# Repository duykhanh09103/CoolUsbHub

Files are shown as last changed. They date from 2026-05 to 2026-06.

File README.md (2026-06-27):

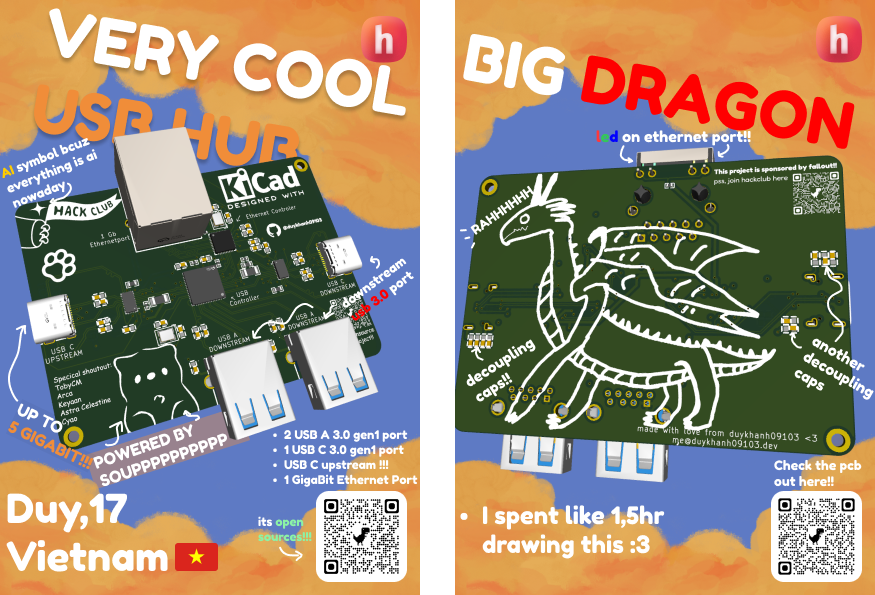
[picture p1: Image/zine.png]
Zine

# Very cool usb hub!!
its a 4 port\* usb 3.0 gen1 hub with usb c as a upstream port. It is fully open source and you can built it yourself!!! \
\*1 of its port is for 1gb ethernet

# Key Features
- Built in **1 Gigabit Ethernet** port using [REALTEK RTL8153B](https://www.lcsc.com/product-detail/C2802072.html)
- **2 USB A** and **1 USB C** 3.0 gen 1 downstream port
- **USB C upstream** so you can use **C to C** and **C to USB** cable!!!(with any length you want)
- Very cool art :3

# Why did i make it?
 currently theres literally no usb hub that does usb c 3.0 as upstream without having its cord built in, its bad and if the cord break u either throw it out or destroy the case to repair it.

# How to use it?
 💀 its an usb hub dude, just plug the usb c upstream to a pc and plug peripheral into the usb c and a port 😭

# 3D image 
- With case: (pss, check it out on [onshape](https://cad.onshape.com/documents/b8187d4a30cc3b22176f8391/w/6bf875d6f0e4efab8544a163/e/2b79dfe3cdb89a71b66a7f8a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))
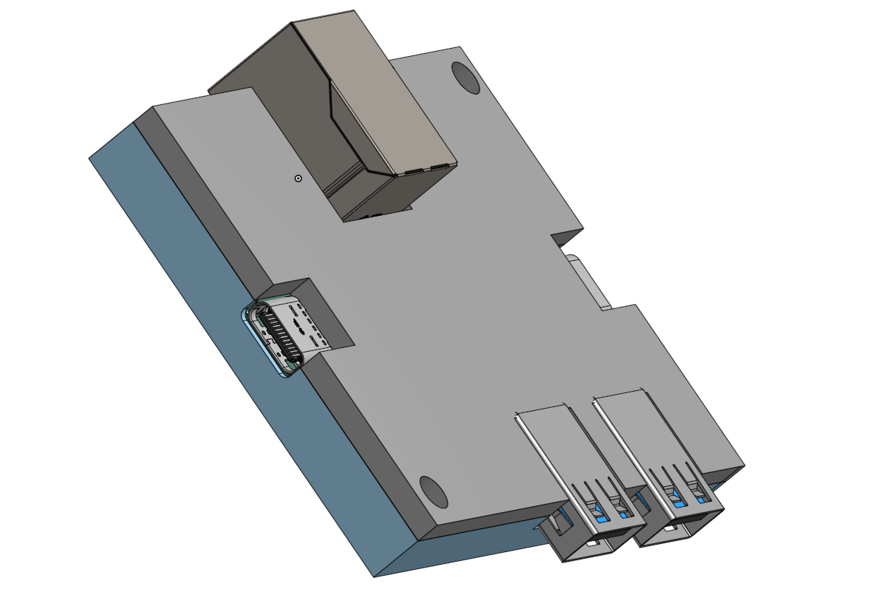
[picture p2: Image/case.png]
case


case 2!!

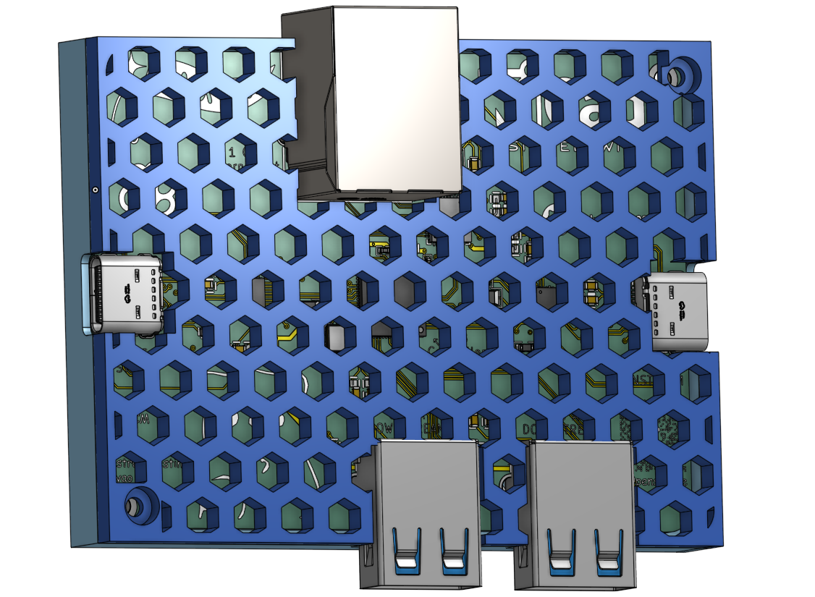
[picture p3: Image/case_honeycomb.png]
case_honeycomb


-Without case

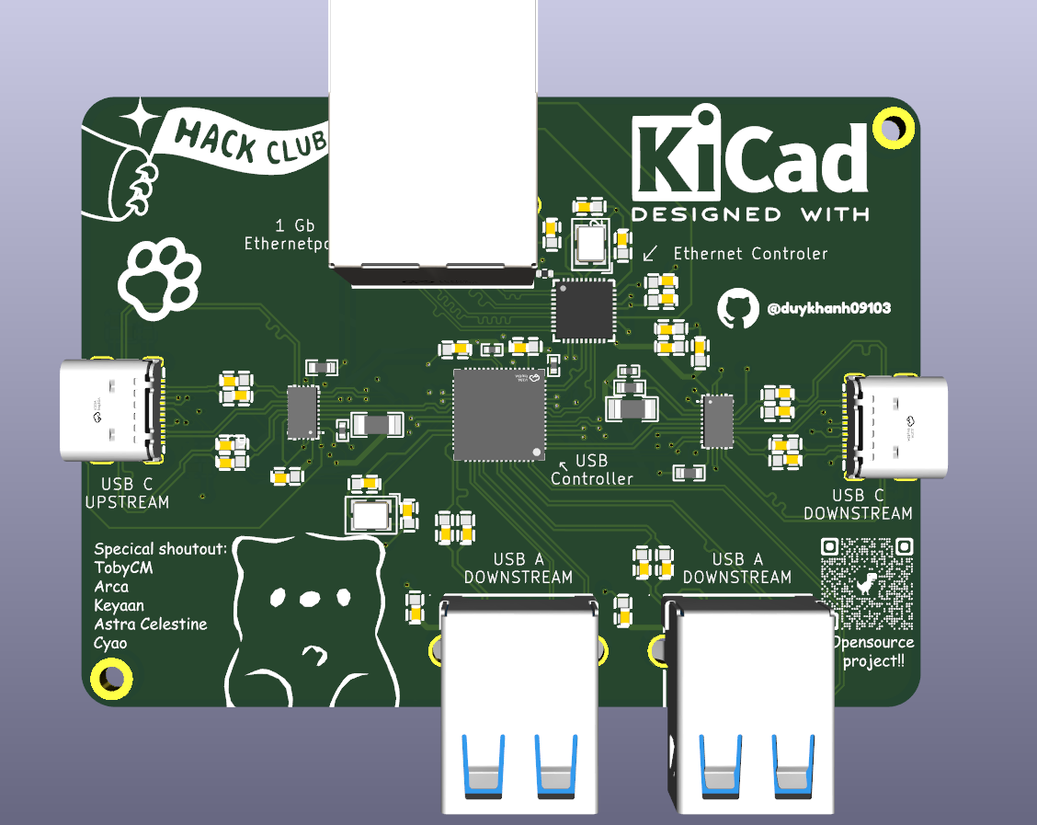
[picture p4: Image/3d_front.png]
3d image


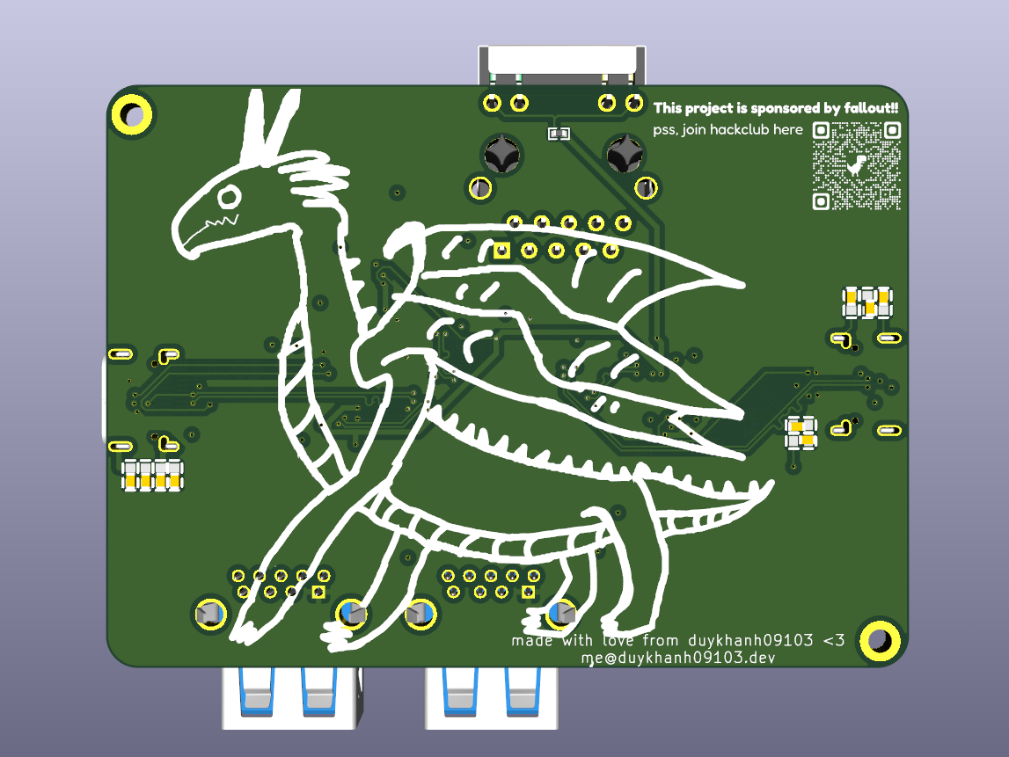
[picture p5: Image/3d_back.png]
3d back image


# SCHEMATIC
 check out the schematic [here](schematic.pdf) if the image is too blurry

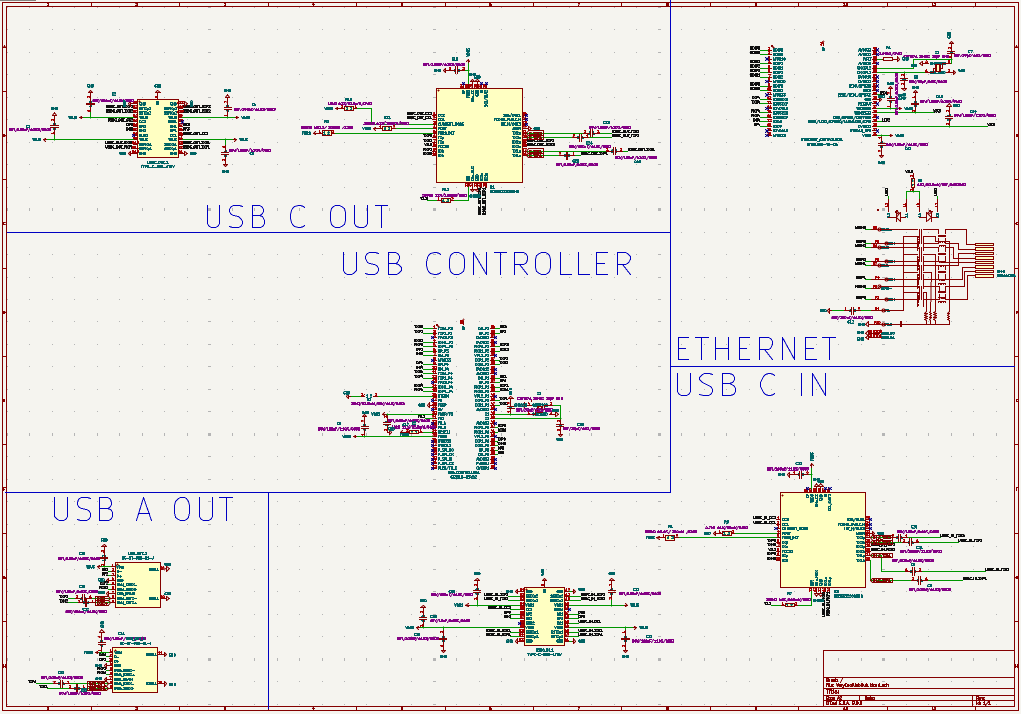
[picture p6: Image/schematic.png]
schematic
 
 
# PCB
 This is a 4 layer pcb made using [Kicad](https://www.kicad.org/), design with attention(😭) to signal intergrity for USB 3 trace! check it out with [kicanvas](https://kicanvas.org/?repo=https%3A%2F%2Fgithub.com%2Fduykhanh09103%2FCoolUsbHub%2Ftree%2Fmain%2Fpcb)!!
 - **Layer 1: signal**

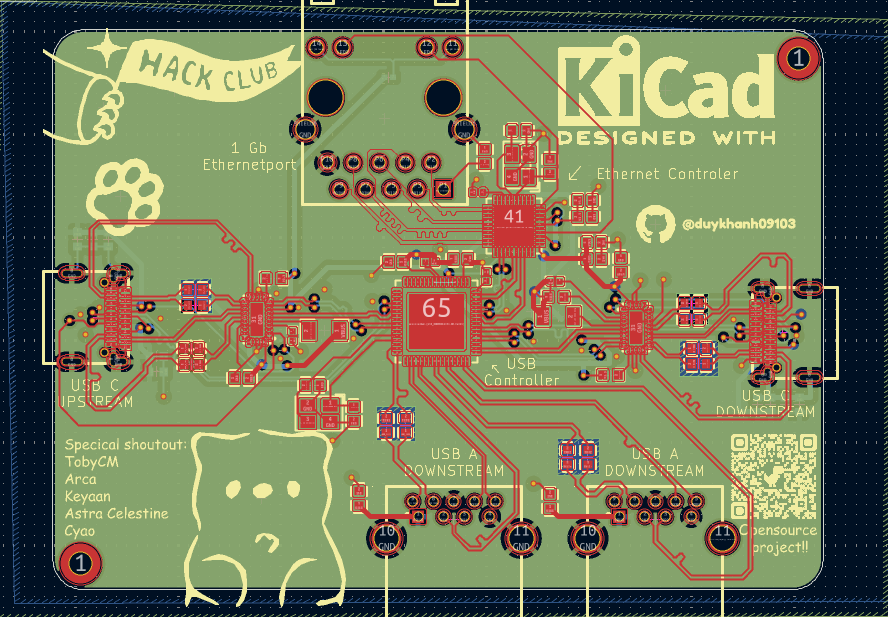
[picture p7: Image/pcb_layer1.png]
layer1
  
 - **Layer 2: Ground**

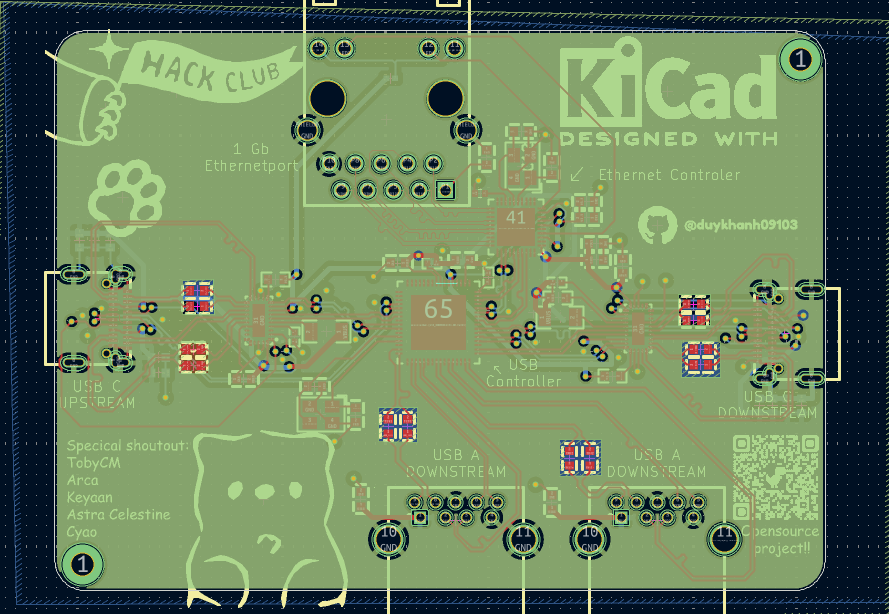
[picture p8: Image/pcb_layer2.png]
layer2
  
 - **Layer 3: Ground**

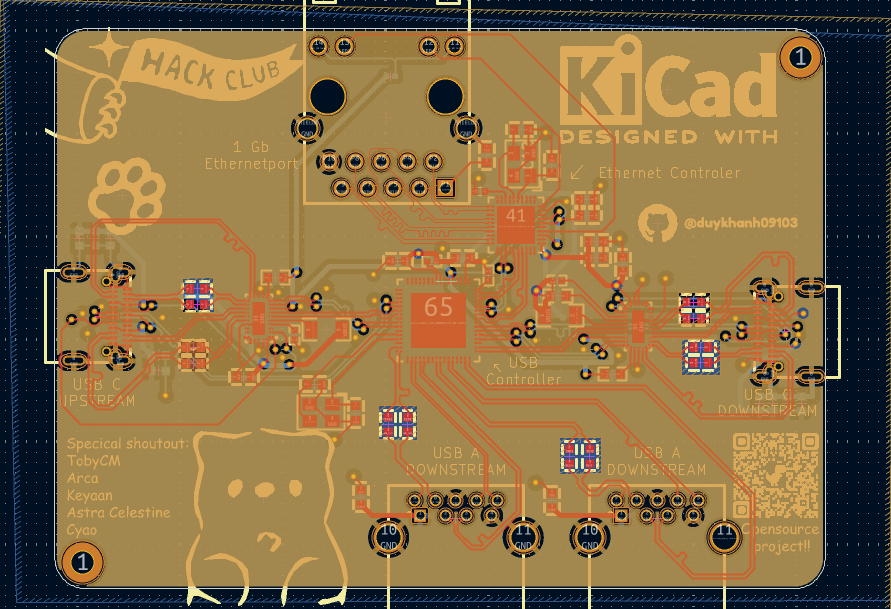
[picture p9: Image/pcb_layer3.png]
layer3
  
 - **Layer 4: Signal/Vbus**
 
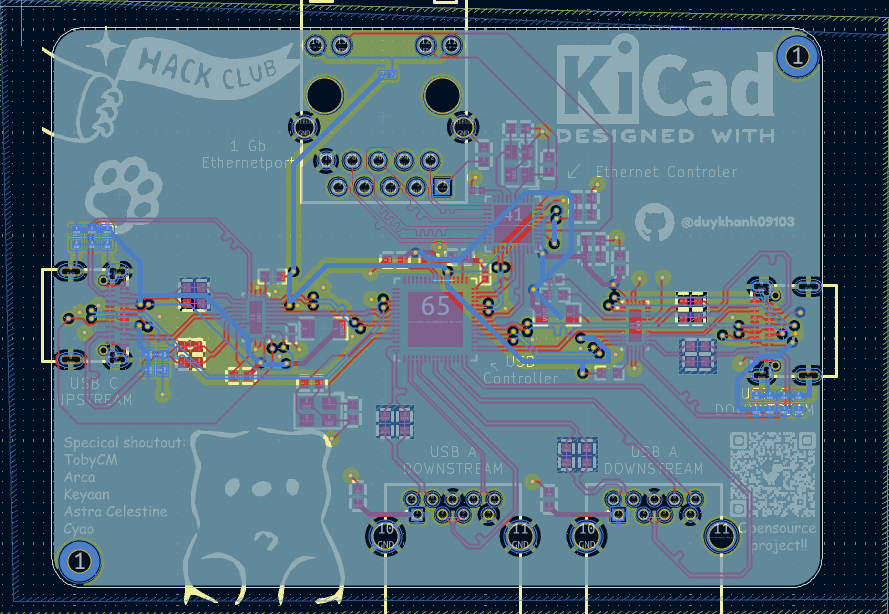
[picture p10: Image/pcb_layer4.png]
layer4
  

# BOM (Bill Of Materials)
> [!IMPORTANT]
> This is the total of the bom including both thing below, do not double count by combining them
> You can leave thing that you already have out of the bom to reduce cost

> [!TIP]
> For any hcer reading this, there is jlc and lcsc cart image in /Image

| Name | Amount | Price | Source/Where To Buy | Note |
|---|---|---|---|---|
| PCB | 5 | $12 | JLCPCB | 4 layer, specify 3313 in stackup(i got white so its 12$) |
| 3D Printed Case | 2 | $2.74 | JLC3DP | |
| PCB Parts | 2 | $30.86| LCSC | |
| Tools and miscellaneous | 1 | $22 | | |
| Shipping | | $11 | | |
| Coupon from fallout | | -$15  | | |
| | | | | |
| Total | | $63.6 | | |

## PCB Parts
> [!IMPORTANT]
> This will include how much components you need to use per 1 PCB and the MOQ (minimum of quanity) you can buy. The price will be listed in MOQ. The final price is included everything except shipping.

> [!WARNING]
>  There might be different capacitor/resistor part from production bom because of out of stock

| Name | Amount | MOQ |  Price  | Note | LCSC Number |
|---|---|-----|---|---|---|
| 39pf 50v 0603 Capacitor | 4 | 100 | $0.48 | | C107049 |
| 10uF 10v 0603 Capacitor | 1 | 20  | $0.53 | | C19702 |
| RTL8153B-VB-CG | 1 | 1 | $3.64 | Ethernet chip (1gb)  | C2802072 |
| 20kΩ 62.5mW 0402 Resistor | 3 | 100 | $0.10 | | C93942 |
| 4.7kΩ 63mW 0402 Resistor  | 1 | 100 | $0.44 | | C509343 |
| RJ45 Jack | 1 | 1 | $2.51 | | C54408 |
| HD3SS3220RNHR | 2 | 1 | $1.9032 | USB TYPE C MUX | C165155 |
| Type C Receptacle | 2 | 5 | $1.60 | on sale | C20883027 |
| GL3510-OSY52 | 1 | 1 | $1.46 | USB HUB | C7501408 |
| Type A Receptacle | 2 | 5 | $0.66 | | C2845330 |
| 25MHz 20pf crystal | 2 | 10  | $0.98 | | C13740 |
| 900kΩ 250mW 1206 Resistor | 1 | 10  | $0.63 | | C871726 |
| 10kΩ 62.5mW 0402 Resistor | 2 | 100 | $0.27 | | C2906861 |
| 1kΩ 62.5mW 0402 Resistor  | 1 | 50  | $0.89 | | C852624 |
| 200kΩ 100mW 0603 Resistor | 2 | 100 | $0.22 | on sale | C2907009 |
| 100nF 50V 0603 Capacitor  | 31 | 50  | $0.92 | | C282518 |
| 2.49k X 0402 Resistor | 1 | 100 | 15k VND | I got it from shopee | X |
| | | | | | |
| Total | | | $19.44  | | |

## Tool and miscellaneous
> [!NOTE]
> If you have the tool already or wanna do this differently, you do not need to buy these

| Name | Amount |  Price | Source |
|---|---|---|---|
| Hot air gun | 1 | $21 | Lazada |
| Flux | 1 | $1 | Shopee |
| Pinecil | 1 | $25.99 | Pinecil official website |
| Solder paste/wire | 1 | $1 | Idk its everywhere |

# How to build??? (soon 👀)
- Order pcb from jlc/any pcb vendor with gerber.zip inside /pcb/production
- there will be video on building one soon

# Credit
 Shoutout to [@tobycm](https://github.com/tobycm) for being the goat and help me a lot with ts project <3\
 This project use kicad, onshape for designing case and pcb\
 Thanks to [Hackclub](https://hackclub.com/) , especially to people running [Fallout](https://fallout.hackclub.com/) for making this project possible :3

# LICENSE
its [MIT](https://opensource.org/license/mit)!! (basically u can do anything with ts). checkout [LICENSE](LICENSE)

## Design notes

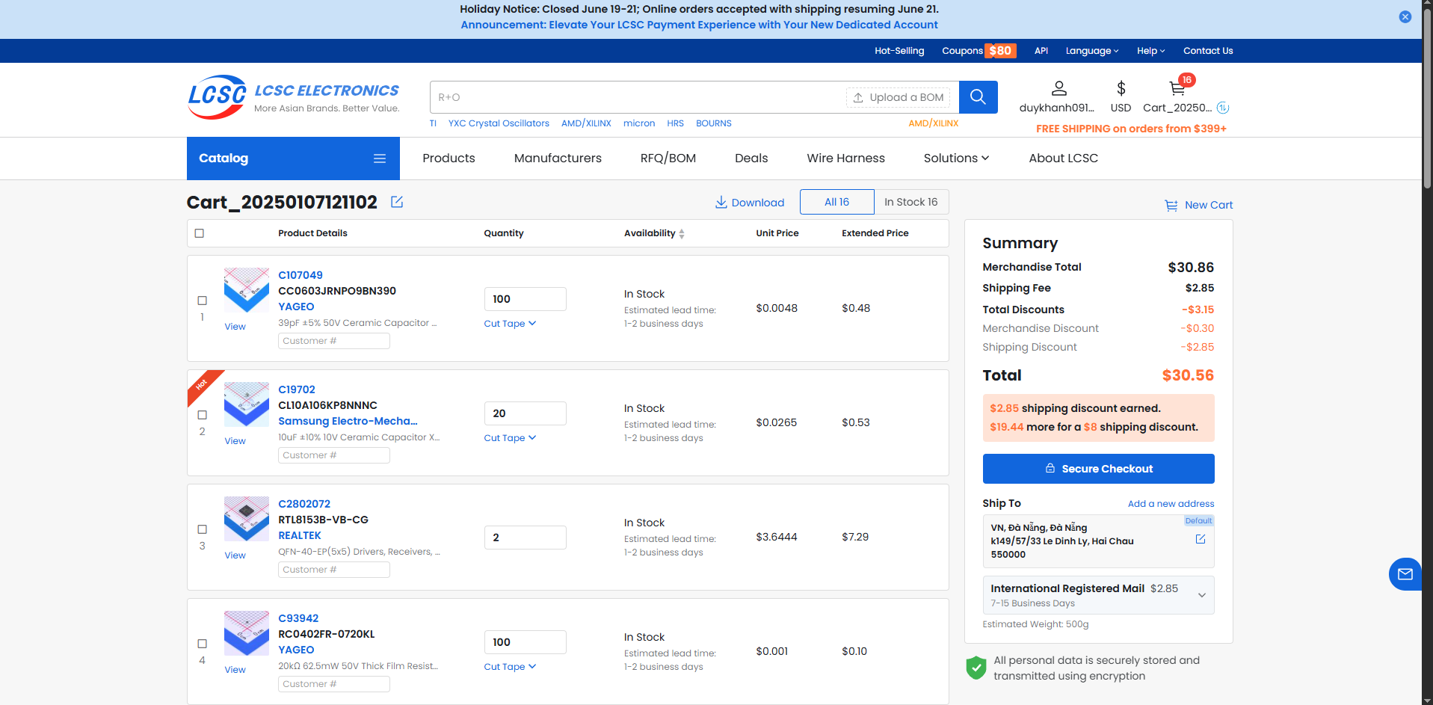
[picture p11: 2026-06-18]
Image/lcsc_cart.png

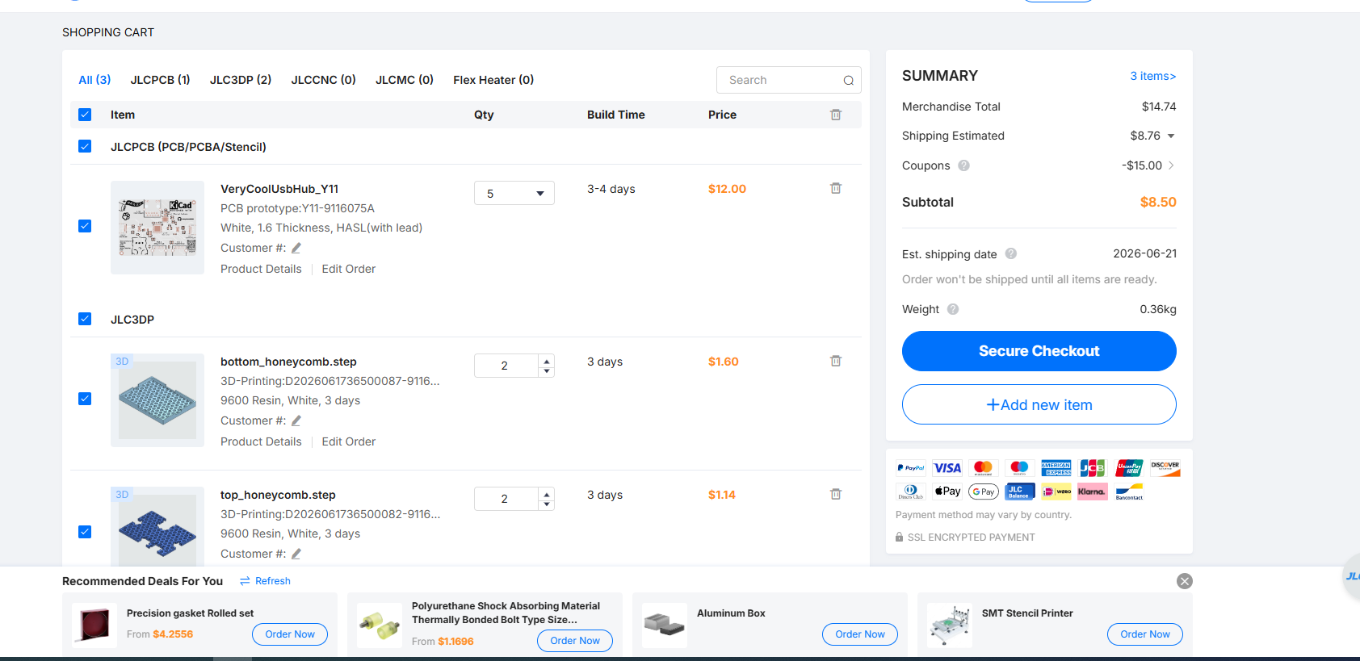
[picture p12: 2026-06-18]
Image/jlc_cart.png

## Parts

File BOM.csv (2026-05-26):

Part | Amount | Price | Link
PCB | 5 | $7 | jlcpcb.com/
100nF Capacitor | 31 | $0.35 | https://www.lcsc.com/product-detail/C14663.html
39 pF Capacitor | 4 | $0.32 | https://www.lcsc.com/product-detail/C107049.html
10 uF Capacitor | 1 | $0.25 | https://www.lcsc.com/product-detail/C19702.html
Ethernet Adapter | 1 | $4.26 | https://www.lcsc.com/product-detail/C2802072.html
10k ohm resistor | 2 | $0.09 | https://www.lcsc.com/product-detail/C60490.html
200k ohm resistor | 2 | $0.16 | https://www.lcsc.com/product-detail/C105574.html
20k ohm resistor | 3 | $0.10 | https://www.lcsc.com/product-detail/C93942.html
1k ohm resistor | 1 | $0.09 | https://www.lcsc.com/product-detail/C106235.html
4.7 k ohm resistor | 1 | $0.34 | https://www.lcsc.com/product-detail/C509343.html
2.49k ohm resistor | 1 | $0.57 | https://shopee.vn/Tr%E1%BB%9F-d%C3%A1n-0402-tr%E1%BB%8B-s%E1%BB%91-trong-2K-(-2K-2.2K-2.26K-2.32K-2.49K-2.55K-2.61K-2.67K-2.7K-2.74K-2.8K-2.87K-)-d%C3%B9ng-ch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
RJ45 connector | 1 | $2.51 | https://www.lcsc.com/product-detail/C54408.html
USB C mux | 2 | $3.89 | https://www.lcsc.com/product-detail/C165155.html
USB C receptacle | 2 | $1.48 | https://www.lcsc.com/product-detail/C20883027.html
USB Controller | 1 | $1.46 | https://www.lcsc.com/product-detail/C7501408.html
25mhz Crystal | 2 | $0.75 | https://www.lcsc.com/product-detail/C13740.html
900k ohm resistor | 1 | $0.45 | https://www.lcsc.com/product-detail/C871726.html
USB A receptacle | 2 | $0.65 | https://www.lcsc.com/product-detail/C2845330.html
Total |  | 24.11$ (shipping not included)

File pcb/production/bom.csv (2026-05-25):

Designator | Footprint | Quantity | Value | LCSC Part #
C1, C10, C11, C12, C13, C14, C15, C16, C17, C19, C2, C20, C21, C22, C23, C24, C26, C29, C3, C30, C31, C32, C33, C34, C35, C36, C37, C4, C5, C8, C9 | C0603 | 31 | CC0603KRX7R9BB104 | C14663
C18, C25, C6, C7 | C0603 | 4 | CC0603JRNPO9BN390 | C107049
C28 | C0603 | 1 | CL10A106KP8NNNC | C19702
ETHERNET_CONTROLLER1 | QFN-40_L5.0-W5.0-P0.40-BL-EP3.7 | 1 | RTL8153B-VB-CG | C2802072
R1, R9 | R1206 | 2 | RT1206BRE07900KL | C871499
R10, R2 | R0402 | 2 | RC0402FR-0710KL | C60490
R11, R12, R7 | R0603 | 3 | RC0603FR-07200KL | C105574
R3 | R0402 | 1 | RC0402FR-0720KL | C93942
R4 | 0402 | 1 | R
R6 | R0402 | 1 | RC0402FR-071KL | C106235
R8 | R0402 | 1 | MCR01MZPF4701 | C509343
RJ45 | RJ45-TH_HR911130A | 1 | HR911130A | C54408
U1, U2 | WQFN-30_L4.5-W2.5-P0.4-BL-EP | 2 | HD3SS3220RNHR | C165155
USBC_IN_1, USBC_OUT_1 | USB-C-SMD_TYPE-C-G05-1TDW | 2 | TYPE-C-G05-1TDW | C20883027
USB_CONTROLLER1 | QFN-64_L8.0-W8.0-P0.40-BL-EP5.4 | 1 | GL3510-OSY52 | C7501408
USB_OUT_1, USB_OUT_2 | USB-3.0-A-TH_HC-ST-003-01-Z | 2 | HC-ST-003-01-J | C2845330
X1, X2 | CRYSTAL-SMD_4P-L3.2-W2.5-BL-2 | 2 | X322525MSB4SI | C13740

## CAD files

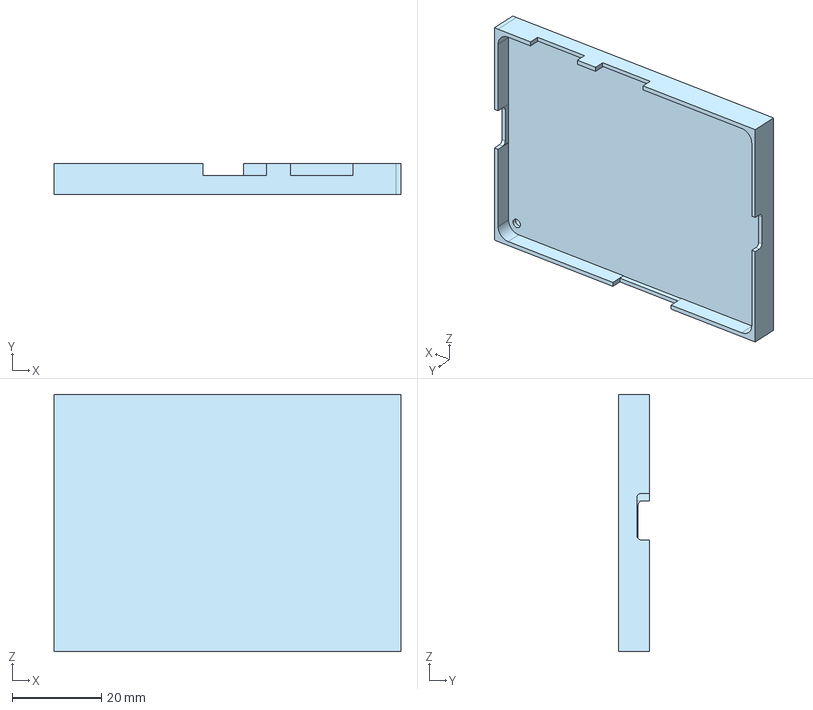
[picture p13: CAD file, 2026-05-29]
3d/bottom.step
77.8 x 7.00 x 57.7 mm

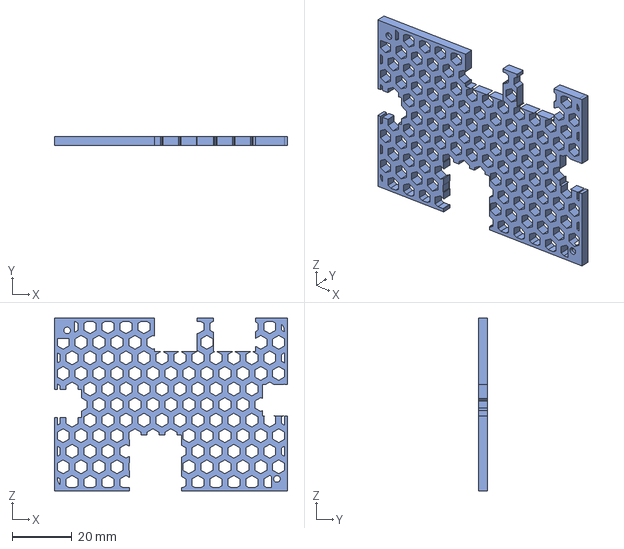
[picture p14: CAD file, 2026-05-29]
3d/top_honeycomb.step
77.8 x 3.00 x 57.7 mm

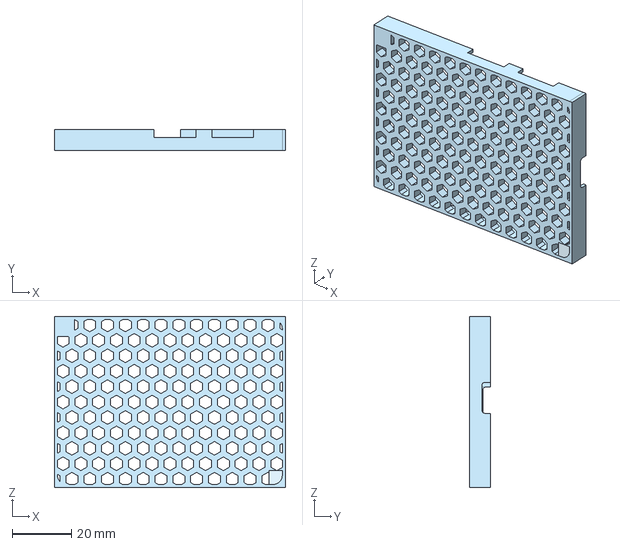
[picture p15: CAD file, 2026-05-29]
3d/bottom_honeycomb.step
77.8 x 7.00 x 57.7 mm

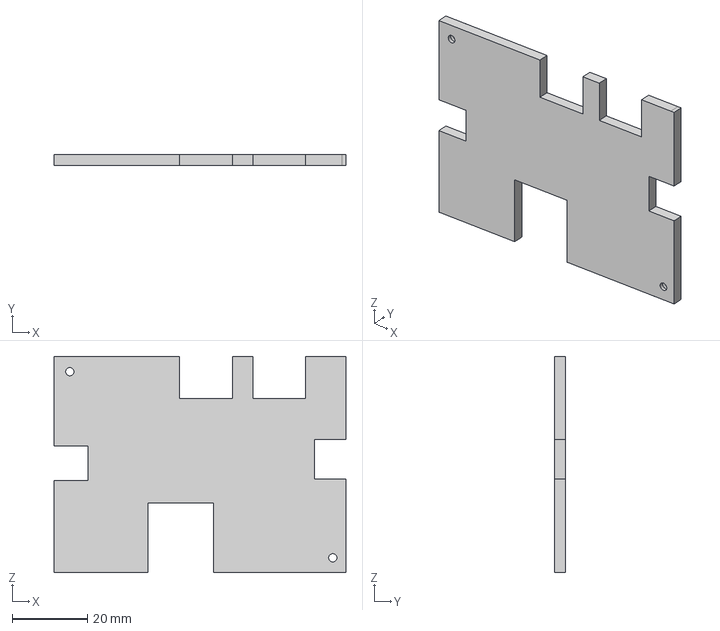
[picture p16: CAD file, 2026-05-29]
3d/top.step
77.8 x 3.00 x 57.7 mm

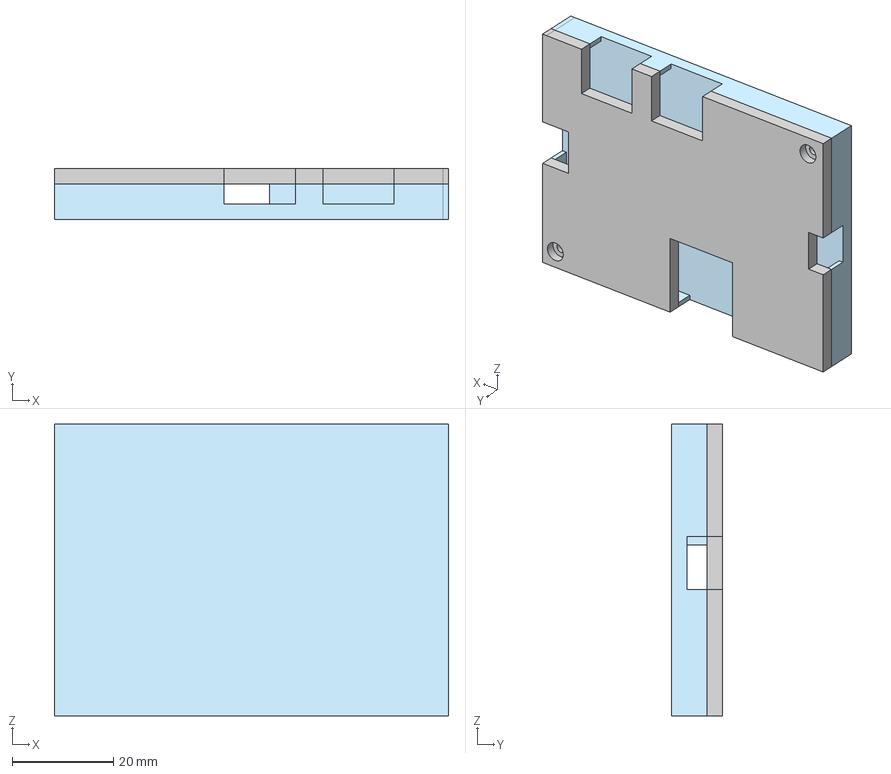
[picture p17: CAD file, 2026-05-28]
3d/case.step
77.8 x 10.0 x 57.7 mm

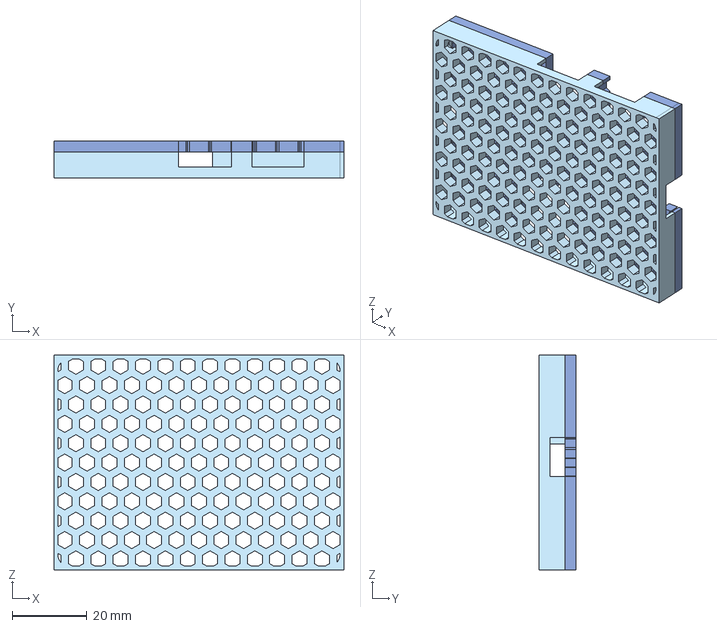
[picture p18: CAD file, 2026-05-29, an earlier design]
3d/old_unpolished/case_honeycomb.step
77.8 x 10.0 x 57.7 mm

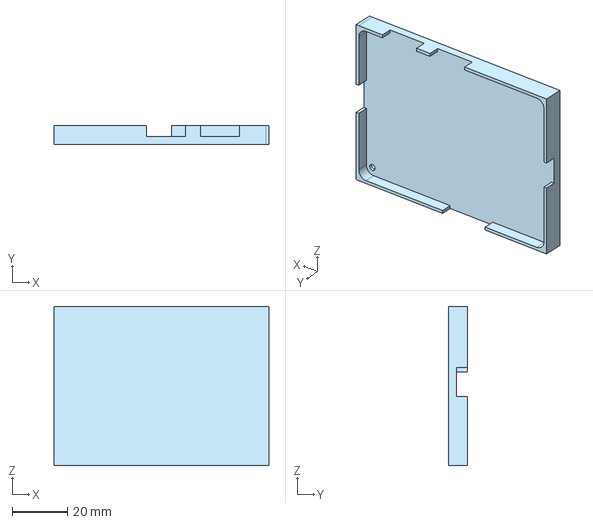
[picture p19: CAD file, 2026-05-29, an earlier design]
3d/old_unpolished/bottom.step
77.8 x 7.00 x 57.7 mm

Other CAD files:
3d/Assembly_case.step
3d/Assembly_honeycomb_case.step
3d/old_unpolished/Bottom_honeycomb.step
3d/old_unpolished/top.step
3d/old_unpolished/Top_honeycomb.step

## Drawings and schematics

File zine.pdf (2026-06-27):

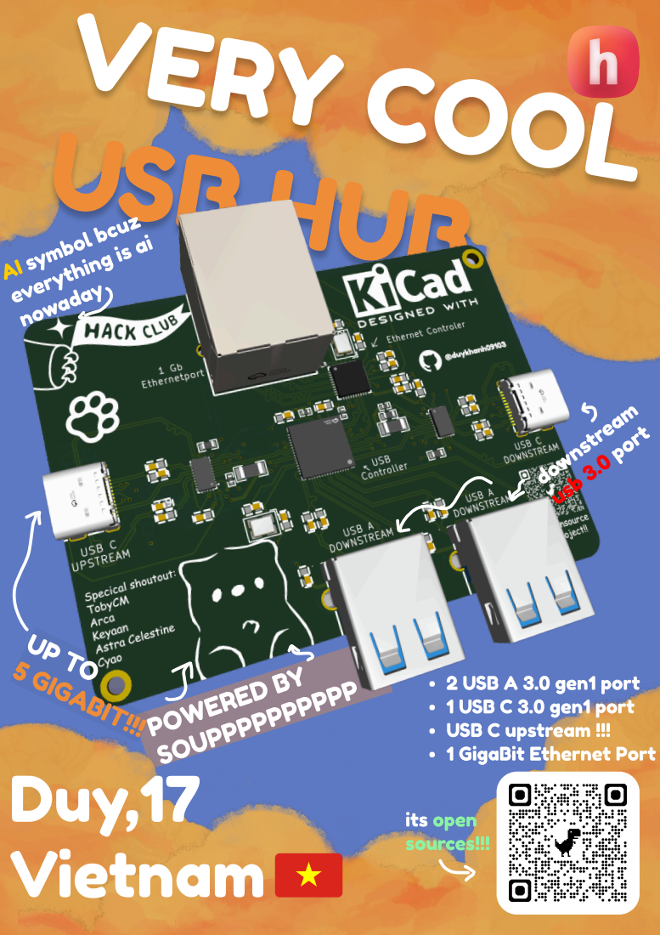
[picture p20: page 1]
nowaday; VERY COOL USB HUB; downstream usb 3.0 port; UP TO 5 GIGABIT!!!; Duy,17; Vietnam; POWERED BY SOUPPPPPPPPPP; its open; sources!!!

AI symbol bcuz

everything is ai

2 USB A 3.0 gen1 port
1 USB C 3.0 gen1 port
USB C upstream !!!
1 GigaBit Ethernet Port

### led on ethernet port!!

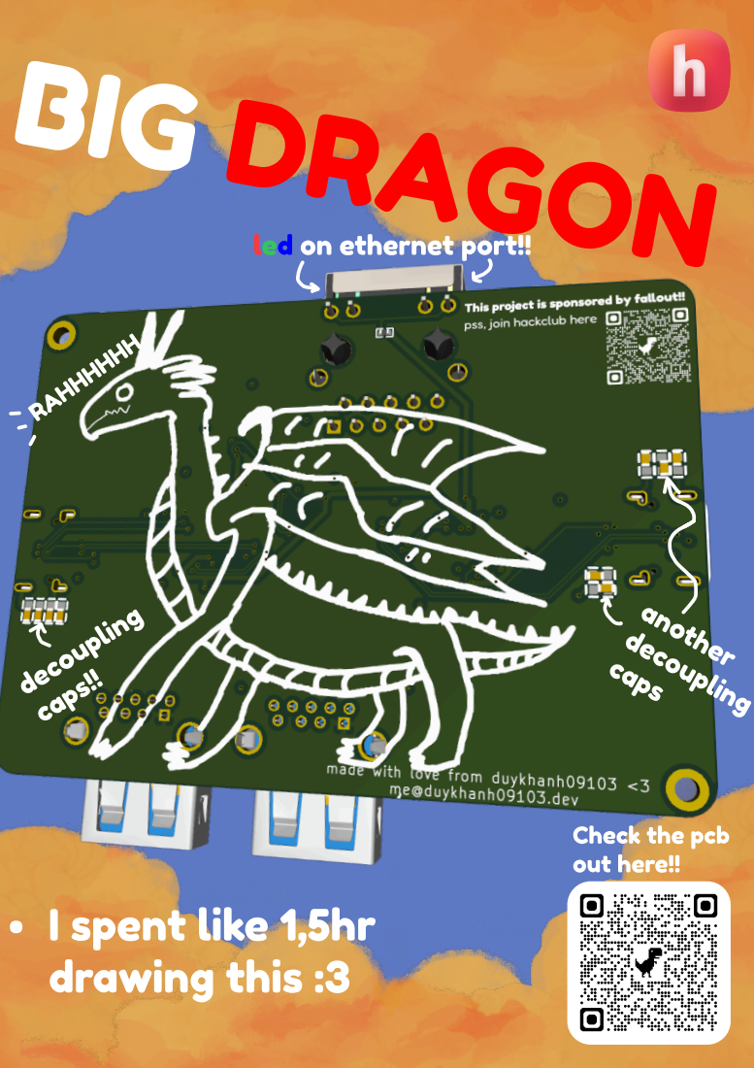
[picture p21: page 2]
BIG DRAGON; RAHHHHHH; decoupling; caps!!; another decoupling caps; I spent like 1,5hr; drawing this :3

Check the pcb
out here!!

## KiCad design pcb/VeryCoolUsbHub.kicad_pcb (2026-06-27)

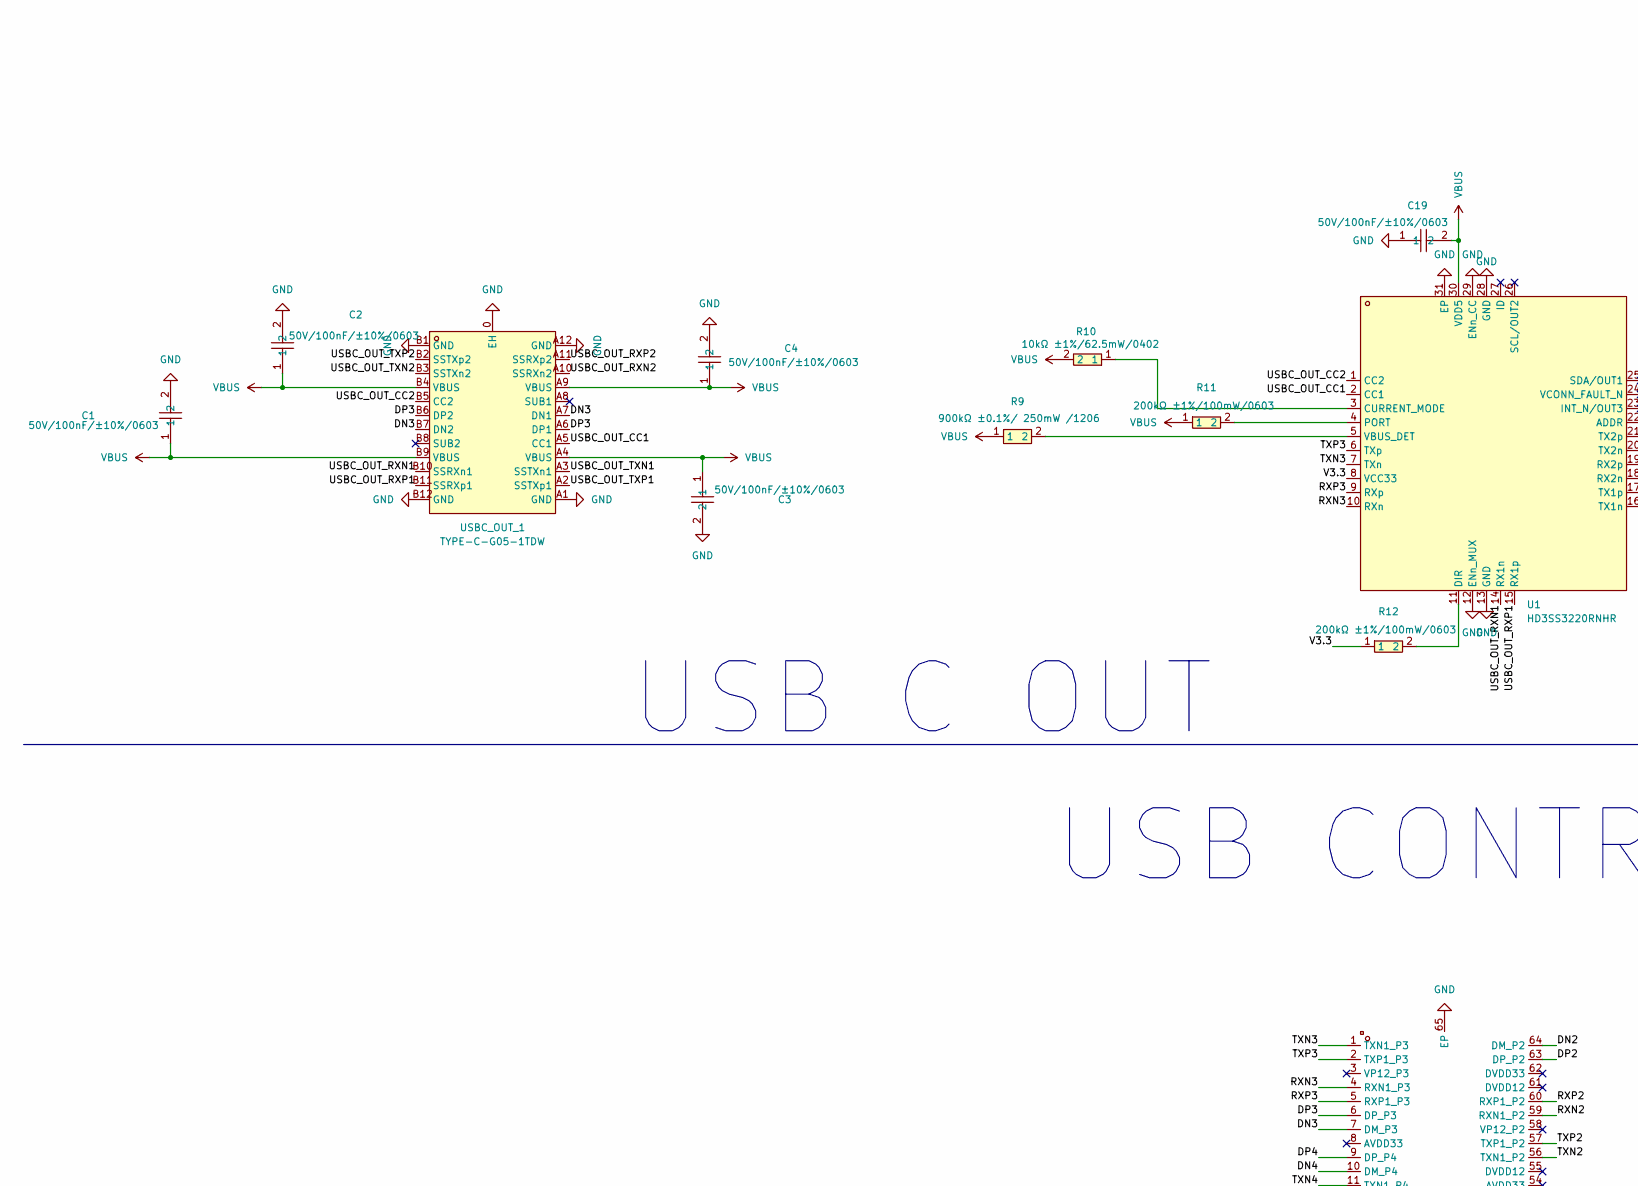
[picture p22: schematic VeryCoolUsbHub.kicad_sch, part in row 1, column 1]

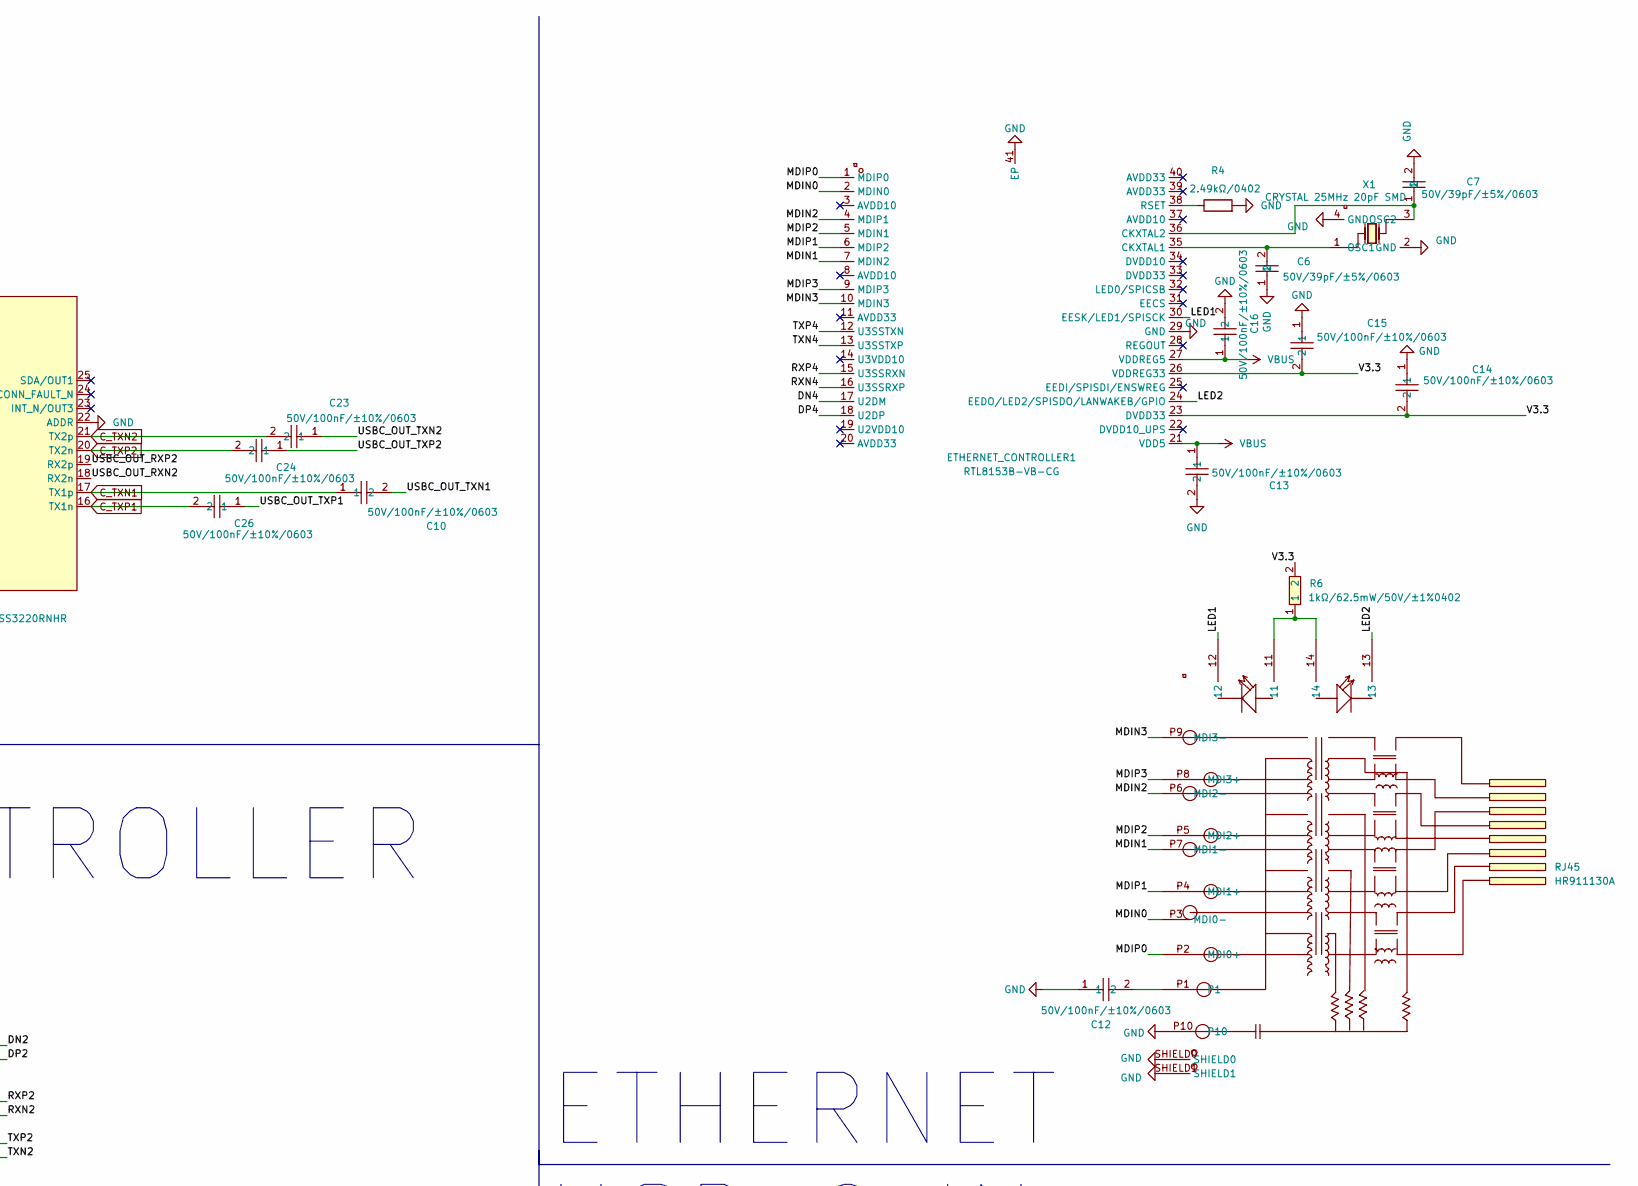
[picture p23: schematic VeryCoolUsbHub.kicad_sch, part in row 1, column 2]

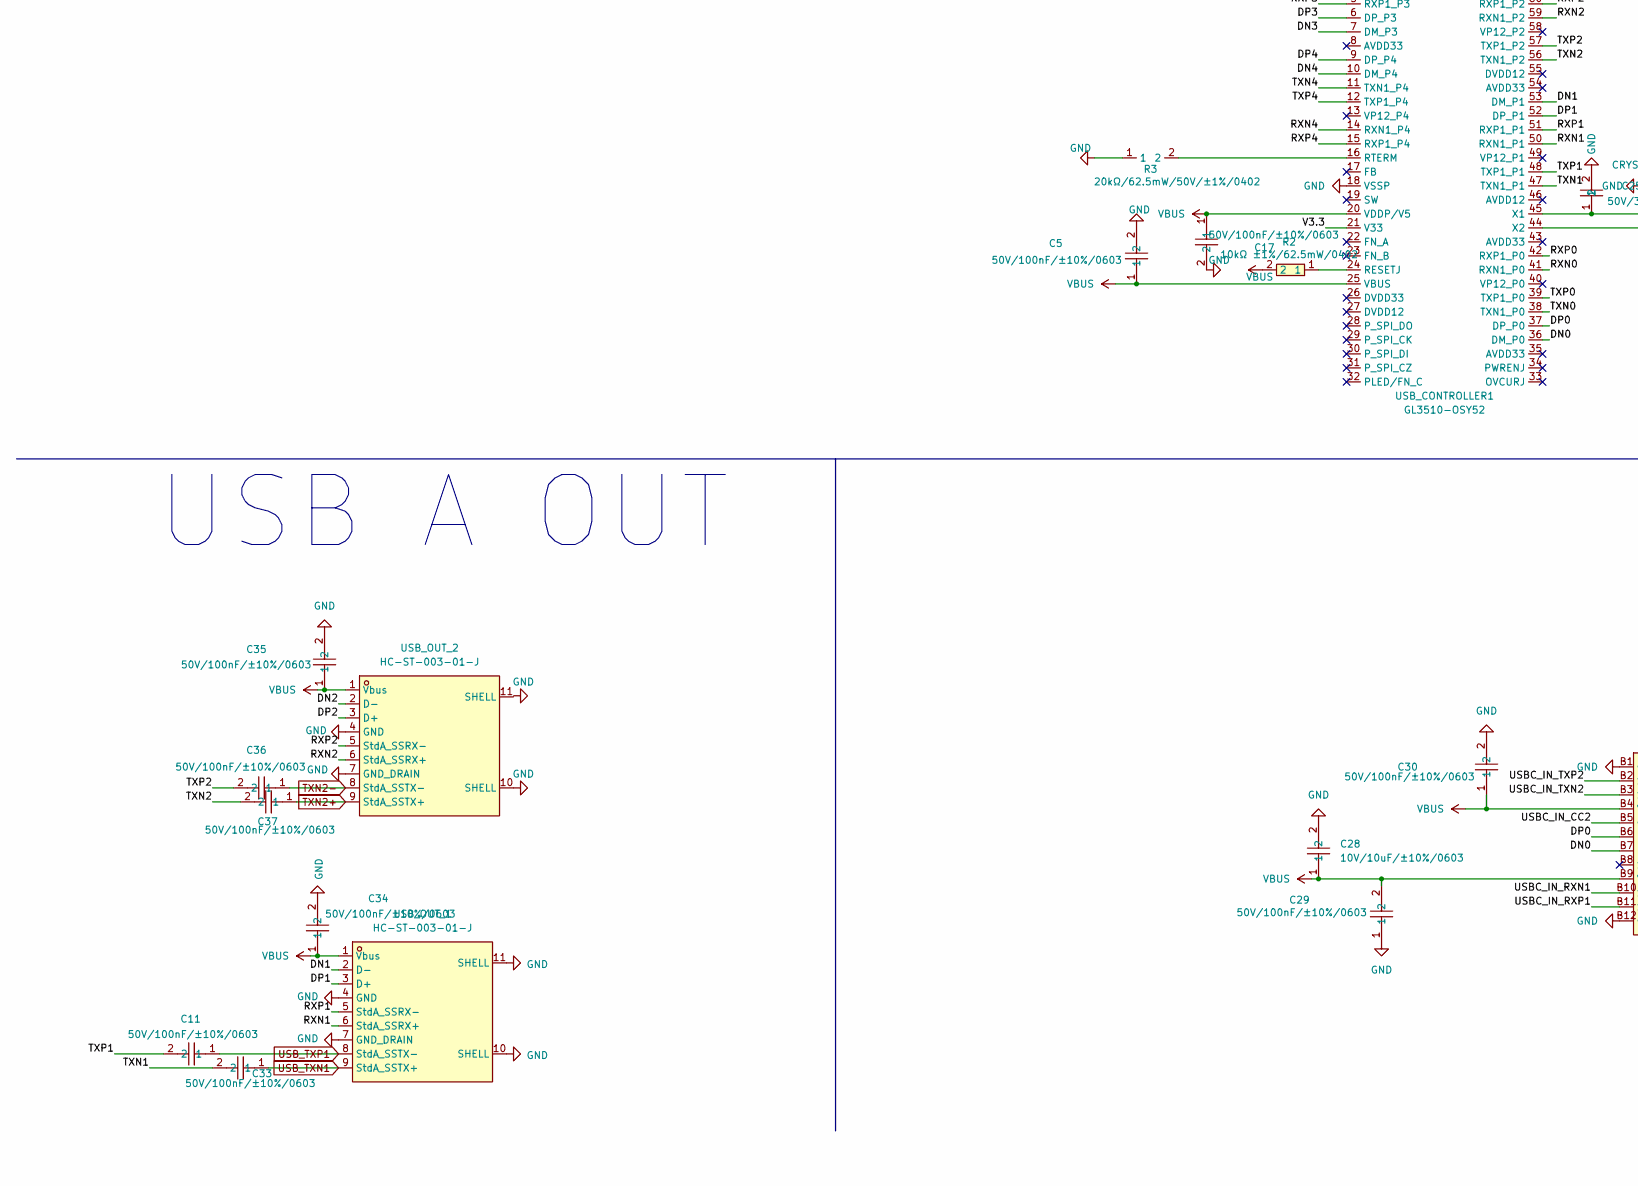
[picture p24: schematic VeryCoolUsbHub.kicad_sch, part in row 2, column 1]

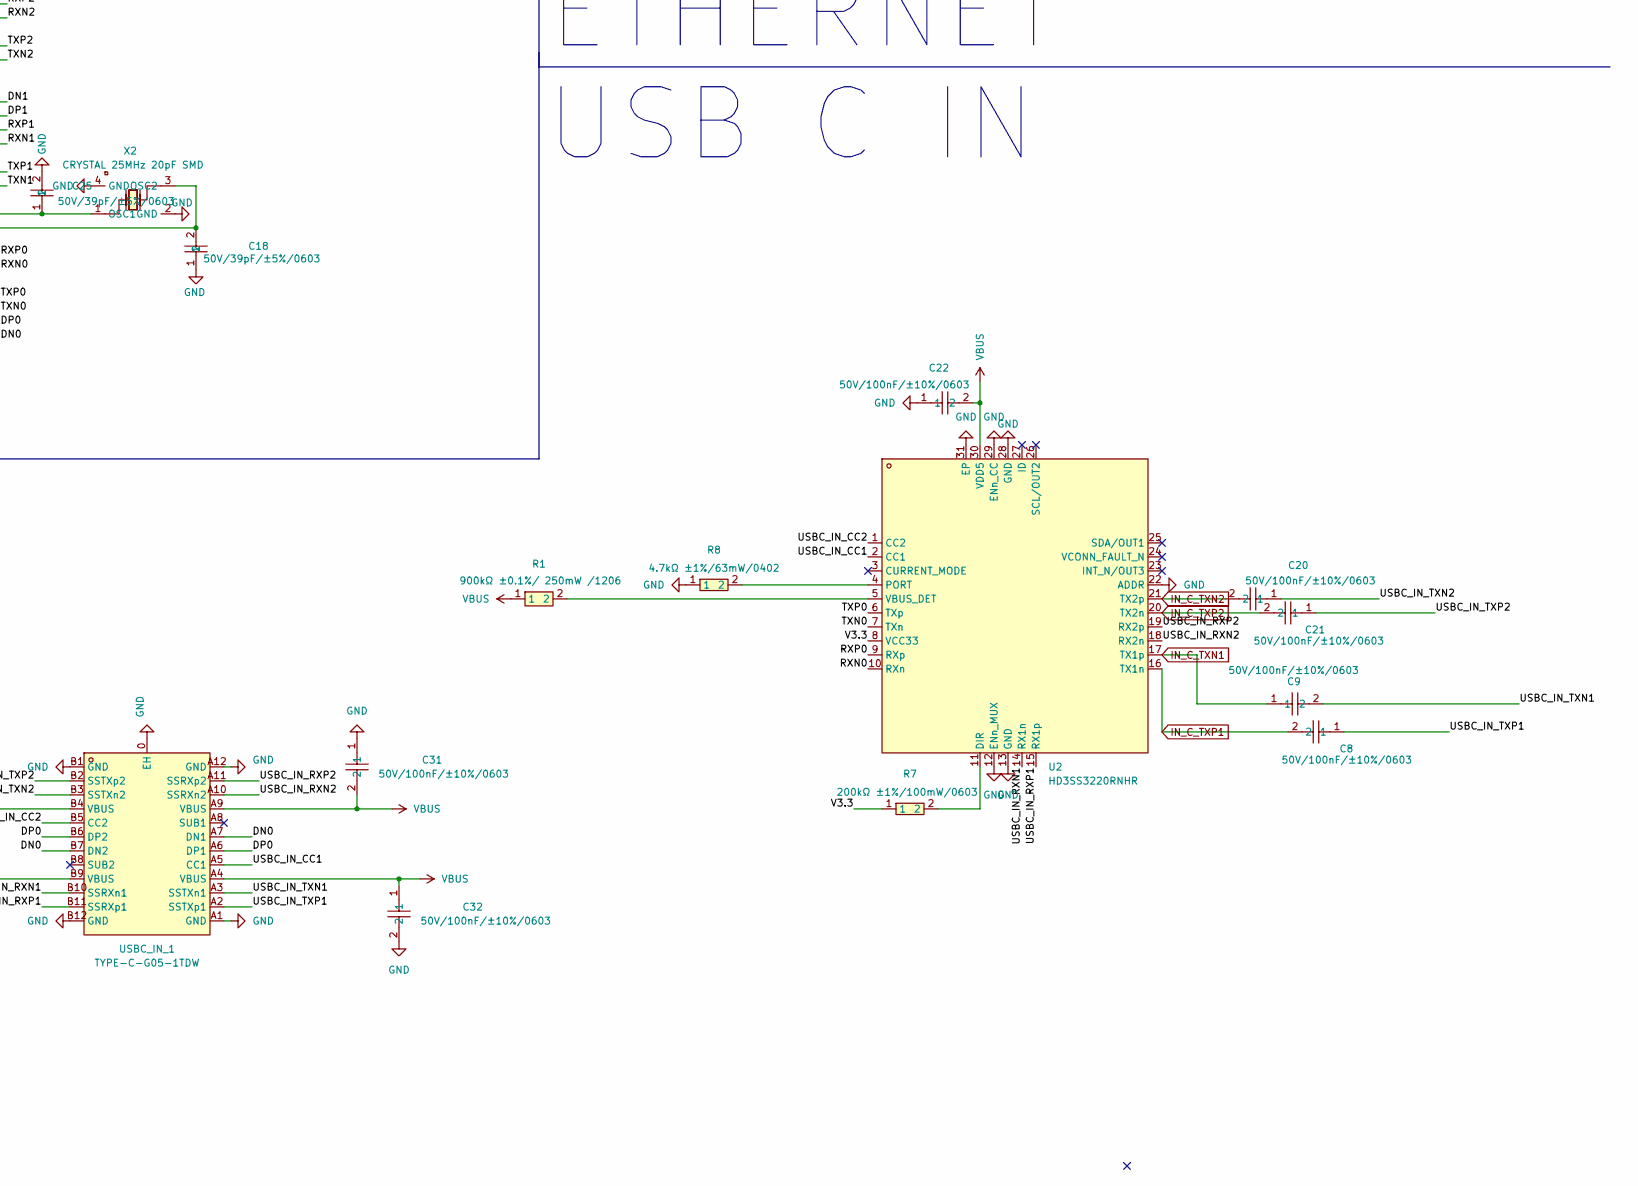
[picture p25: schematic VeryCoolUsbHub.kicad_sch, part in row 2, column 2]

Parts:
C1, C2, C3, C4, C5, C8, C9, C10, C11, C12, C13, C14, C15, C16, C17, C19, C20, C21, C22, C23, C24, C26, C29, C30, C31, C32, C33, C34, C35, C36, C37: CC0603KRX7R9BB104; C0603; LCSC Part C14663
C6, C7, C18, C25: CC0603JRNPO9BN390; C0603; LCSC Part C107049
C28: CL10A106KP8NNNC; C0603; LCSC Part C19702
ETHERNET_CONTROLLER1: RTL8153B-VB-CG; QFN-40_L5.0-W5.0-P0.40-BL-EP3.7; LCSC Part C2802072
R1, R9: RT1206BRE07900KL; R1206; MPN RT1206BRE07900KL; LCSC Part C871499
R2, R10: RC0402FR-0710KL; R0402; MPN RC0402FR-0710KL; LCSC Part C60490
R3: RC0402FR-0720KL; R0402; LCSC Part C93942
R4: R; R_0402_1005Metric
R6: RC0402FR-071KL; R0402; LCSC Part C106235
R7, R11, R12: RC0603FR-07200KL; R0603; MPN RC0603FR-07200KL; LCSC Part C105574
R8: MCR01MZPF4701; R0402; MPN MCR01MZPF4701; LCSC Part C509343
RJ45: HR911130A; RJ45-TH_HR911130A; LCSC Part C54408
U1, U2: HD3SS3220RNHR; WQFN-30_L4.5-W2.5-P0.4-BL-EP; MPN HD3SS3220RNHR; LCSC Part C165155
USBC_IN_1: TYPE-C-G05-1TDW; USB-C-SMD_TYPE-C-G05-1TDW; MPN TYPE-C-G05-1TDW; LCSC Part C20883027
USBC_OUT_1: TYPE-C-G05-1TDW; USB-C-SMD_TYPE-C-G05-1TDW; MPN TYPE-C-G05-1TDW; LCSC Part C20883027
USB_CONTROLLER1: GL3510-OSY52; QFN-64_L8.0-W8.0-P0.40-BL-EP5.4; LCSC Part C7501408
USB_OUT_1, USB_OUT_2: HC-ST-003-01-J; USB-3.0-A-TH_HC-ST-003-01-Z; MPN HC-ST-003-01-J; LCSC Part C2845330
X1, X2: X322525MSB4SI; CRYSTAL-SMD_4P-L3.2-W2.5-BL-2; LCSC Part C13740

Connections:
/DN0: USBC_IN_1.A7 (DN1), USBC_IN_1.B7 (DN2), USB_CONTROLLER1.36 (DM_P0)
/DN1: USB_CONTROLLER1.53 (DM_P1), USB_OUT_1.2 (D-)
/DN2: USB_CONTROLLER1.64 (DM_P2), USB_OUT_2.2 (D-)
/DN3: USBC_OUT_1.A7 (DN1), USBC_OUT_1.B7 (DN2), USB_CONTROLLER1.7 (DM_P3)
/DN4: ETHERNET_CONTROLLER1.17 (U2DM), USB_CONTROLLER1.10 (DM_P4)
/DP0: USBC_IN_1.A6 (DP1), USBC_IN_1.B6 (DP2), USB_CONTROLLER1.37 (DP_P0)
/DP1: USB_CONTROLLER1.52 (DP_P1), USB_OUT_1.3 (D+)
/DP2: USB_CONTROLLER1.63 (DP_P2), USB_OUT_2.3 (D+)
/DP3: USBC_OUT_1.A6 (DP1), USBC_OUT_1.B6 (DP2), USB_CONTROLLER1.6 (DP_P3)
/DP4: ETHERNET_CONTROLLER1.18 (U2DP), USB_CONTROLLER1.9 (DP_P4)
/LED1: ETHERNET_CONTROLLER1.30 (EESK/LED1/SPISCK), RJ45.12
/LED2: ETHERNET_CONTROLLER1.24 (EEDO/LED2/SPISDO/LANWAKEB/GPIO), RJ45.13
/MDIN0: ETHERNET_CONTROLLER1.2 (MDIN0), RJ45.P3 (MDI0-)
/MDIN1: ETHERNET_CONTROLLER1.7 (MDIN2), RJ45.P7 (MDI1-)
/MDIN2: ETHERNET_CONTROLLER1.4 (MDIP1), RJ45.P6 (MDI2-)
/MDIN3: ETHERNET_CONTROLLER1.10 (MDIN3), RJ45.P9 (MDI3-)
/MDIP0: ETHERNET_CONTROLLER1.1 (MDIP0), RJ45.P2 (MDI0+)
/MDIP1: ETHERNET_CONTROLLER1.6 (MDIP2), RJ45.P4 (MDI1+)
/MDIP2: ETHERNET_CONTROLLER1.5 (MDIN1), RJ45.P5 (MDI2+)
/MDIP3: ETHERNET_CONTROLLER1.9 (MDIP3), RJ45.P8 (MDI3+)
/RXN0: U2.10 (RXn), USB_CONTROLLER1.41 (RXN1_P0)
/RXN1: USB_CONTROLLER1.50 (RXN1_P1), USB_OUT_1.6 (StdA_SSRX+)
/RXN2: USB_CONTROLLER1.59 (RXN1_P2), USB_OUT_2.6 (StdA_SSRX+)
/RXN3: U1.10 (RXn), USB_CONTROLLER1.4 (RXN1_P3)
/RXN4: ETHERNET_CONTROLLER1.16 (U3SSRXP), USB_CONTROLLER1.14 (RXN1_P4)
/RXP0: U2.9 (RXp), USB_CONTROLLER1.42 (RXP1_P0)
/RXP1: USB_CONTROLLER1.51 (RXP1_P1), USB_OUT_1.5 (StdA_SSRX-)
/RXP2: USB_CONTROLLER1.60 (RXP1_P2), USB_OUT_2.5 (StdA_SSRX-)
/RXP3: U1.9 (RXp), USB_CONTROLLER1.5 (RXP1_P3)
/RXP4: ETHERNET_CONTROLLER1.15 (U3SSRXN), USB_CONTROLLER1.15 (RXP1_P4)
/TXN0: U2.7 (TXn), USB_CONTROLLER1.38 (TXN1_P0)
/TXN1: C33.2, USB_CONTROLLER1.47 (TXN1_P1)
/TXN2: C37.2, USB_CONTROLLER1.56 (TXN1_P2)
/TXN3: U1.7 (TXn), USB_CONTROLLER1.1 (TXN1_P3)
/TXN4: ETHERNET_CONTROLLER1.13 (U3SSTXP), USB_CONTROLLER1.11 (TXN1_P4)
/TXP0: U2.6 (TXp), USB_CONTROLLER1.39 (TXP1_P0)
/TXP1: C11.2, USB_CONTROLLER1.48 (TXP1_P1)
/TXP2: C36.2, USB_CONTROLLER1.57 (TXP1_P2)
/TXP3: U1.6 (TXp), USB_CONTROLLER1.2 (TXP1_P3)
/TXP4: ETHERNET_CONTROLLER1.12 (U3SSTXN), USB_CONTROLLER1.12 (TXP1_P4)
/USBC_IN_CC1: U2.2 (CC1), USBC_IN_1.A5 (CC1)
/USBC_IN_CC2: U2.1 (CC2), USBC_IN_1.B5 (CC2)
/USBC_IN_RXN1: U2.14 (RX1n), USBC_IN_1.B10 (SSRXn1)
/USBC_IN_RXN2: U2.18 (RX2n), USBC_IN_1.A10 (SSRXn2)
/USBC_IN_RXP1: U2.15 (RX1p), USBC_IN_1.B11 (SSRXp1)
/USBC_IN_RXP2: U2.19 (RX2p), USBC_IN_1.A11 (SSRXp2)
/USBC_IN_TXN1: C9.2, USBC_IN_1.A3 (SSTXn1)
/USBC_IN_TXN2: C20.1, USBC_IN_1.B3 (SSTXn2)
/USBC_IN_TXP1: C8.1, USBC_IN_1.A2 (SSTXp1)
/USBC_IN_TXP2: C21.1, USBC_IN_1.B2 (SSTXp2)
/USBC_OUT_CC1: U1.2 (CC1), USBC_OUT_1.A5 (CC1)
/USBC_OUT_CC2: U1.1 (CC2), USBC_OUT_1.B5 (CC2)
/USBC_OUT_RXN1: U1.14 (RX1n), USBC_OUT_1.B10 (SSRXn1)
/USBC_OUT_RXN2: U1.18 (RX2n), USBC_OUT_1.A10 (SSRXn2)
/USBC_OUT_RXP1: U1.15 (RX1p), USBC_OUT_1.B11 (SSRXp1)
/USBC_OUT_RXP2: U1.19 (RX2p), USBC_OUT_1.A11 (SSRXp2)
/USBC_OUT_TXN1: C10.2, USBC_OUT_1.A3 (SSTXn1)
/USBC_OUT_TXN2: C23.1, USBC_OUT_1.B3 (SSTXn2)
/USBC_OUT_TXP1: C26.1, USBC_OUT_1.A2 (SSTXp1)
/USBC_OUT_TXP2: C24.1, USBC_OUT_1.B2 (SSTXp2)
/V3.3: C14.2, C15.2, ETHERNET_CONTROLLER1.23 (DVDD33), ETHERNET_CONTROLLER1.26 (VDDREG33), R6.2, R7.1, R12.1, U1.8 (VCC33), U2.8 (VCC33), USB_CONTROLLER1.21 (V33)
C_TXN1: C10.1, U1.17 (TX1p)
C_TXN2: C23.2, U1.21 (TX2p)
C_TXP1: C26.2, U1.16 (TX1n)
C_TXP2: C24.2, U1.20 (TX2n)
GND: C1.2, C2.2, C3.2, C4.2, C5.2, C6.1, C7.2, C12.1, C13.2, C14.1, C15.1, C16.2, C17.2, C18.1, C19.1, C22.1, C25.2, C28.2, C29.1, C30.2, C31.1, C32.2, C34.2, C35.2, ETHERNET_CONTROLLER1.29 (GND), ETHERNET_CONTROLLER1.41 (EP), R3.1, R4.2, R8.1, RJ45.P10, RJ45.SHIELD0, RJ45.SHIELD1, U1.12 (ENn_MUX), U1.13 (GND), U1.22 (ADDR), U1.28 (GND), U1.29 (ENn_CC), U1.31 (EP), U2.12 (ENn_MUX), U2.13 (GND), U2.22 (ADDR), U2.28 (GND), U2.29 (ENn_CC), U2.31 (EP), USBC_IN_1.0 (EH), USBC_IN_1.A1 (GND), USBC_IN_1.A12 (GND), USBC_IN_1.B1 (GND), USBC_IN_1.B12 (GND), USBC_OUT_1.0 (EH), USBC_OUT_1.A1 (GND), USBC_OUT_1.A12 (GND), USBC_OUT_1.B1 (GND), USBC_OUT_1.B12 (GND), USB_CONTROLLER1.18 (VSSP), USB_CONTROLLER1.65 (EP), USB_OUT_1.4 (GND), USB_OUT_1.7 (GND_DRAIN), USB_OUT_1.10 (SHELL), USB_OUT_1.11 (SHELL), USB_OUT_2.4 (GND), USB_OUT_2.7 (GND_DRAIN), USB_OUT_2.10 (SHELL), X1.2 (GND), X1.4 (GND), X2.2 (GND), X2.4 (GND)
IN_C_TXN1: C9.1, U2.17 (TX1p)
IN_C_TXN2: C20.2, U2.21 (TX2p)
IN_C_TXP1: C8.2, U2.16 (TX1n)
IN_C_TXP2: C21.2, U2.20 (TX2n)
unnamed: C12.2, RJ45.P1
unnamed: C6.2, ETHERNET_CONTROLLER1.35 (CKXTAL1), X1.1 (OSC1)
unnamed: C7.1, ETHERNET_CONTROLLER1.36 (CKXTAL2), X1.3 (OSC2)
unnamed: ETHERNET_CONTROLLER1.38 (RSET), R4.1
unnamed: R6.1, RJ45.11, RJ45.14
unnamed: R10.1, U1.3 (CURRENT_MODE)
unnamed: R12.2, U1.11 (DIR)
unnamed: R11.2, U1.4 (PORT)
unnamed: R9.2, U1.5 (VBUS_DET)
unnamed: R7.2, U2.11 (DIR)
unnamed: R8.2, U2.4 (PORT)
unnamed: R1.2, U2.5 (VBUS_DET)
unnamed: R2.1, USB_CONTROLLER1.24 (RESETJ)
unnamed: R3.2, USB_CONTROLLER1.16 (RTERM)
unnamed: C25.1, USB_CONTROLLER1.45 (X1), X2.1 (OSC1)
unnamed: C18.2, USB_CONTROLLER1.44 (X2), X2.3 (OSC2)
TXN2+: C37.1, USB_OUT_2.9 (StdA_SSTX+)
TXN2-: C36.1, USB_OUT_2.8 (StdA_SSTX-)
USB_TXN1: C33.1, USB_OUT_1.9 (StdA_SSTX+)
USB_TXP1: C11.1, USB_OUT_1.8 (StdA_SSTX-)
VBUS: C1.1, C2.1, C3.1, C4.1, C5.1, C13.1, C16.1, C17.1, C19.2, C22.2, C28.1, C29.2, C30.1, C31.2, C32.1, C34.1, C35.1, ETHERNET_CONTROLLER1.21 (VDD5), ETHERNET_CONTROLLER1.27 (VDDREG5), R1.1, R2.2, R9.1, R10.2, R11.1, U1.30 (VDD5), U2.30 (VDD5), USBC_IN_1.A4 (VBUS), USBC_IN_1.A9 (VBUS), USBC_IN_1.B4 (VBUS), USBC_IN_1.B9 (VBUS), USBC_OUT_1.A4 (VBUS), USBC_OUT_1.A9 (VBUS), USBC_OUT_1.B4 (VBUS), USBC_OUT_1.B9 (VBUS), USB_CONTROLLER1.20 (VDDP/V5), USB_CONTROLLER1.25 (VBUS), USB_OUT_1.1 (Vbus), USB_OUT_2.1 (Vbus)

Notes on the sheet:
USB A OUT
ETHERNET
USB CONTROLLER
USB C OUT
USB C IN

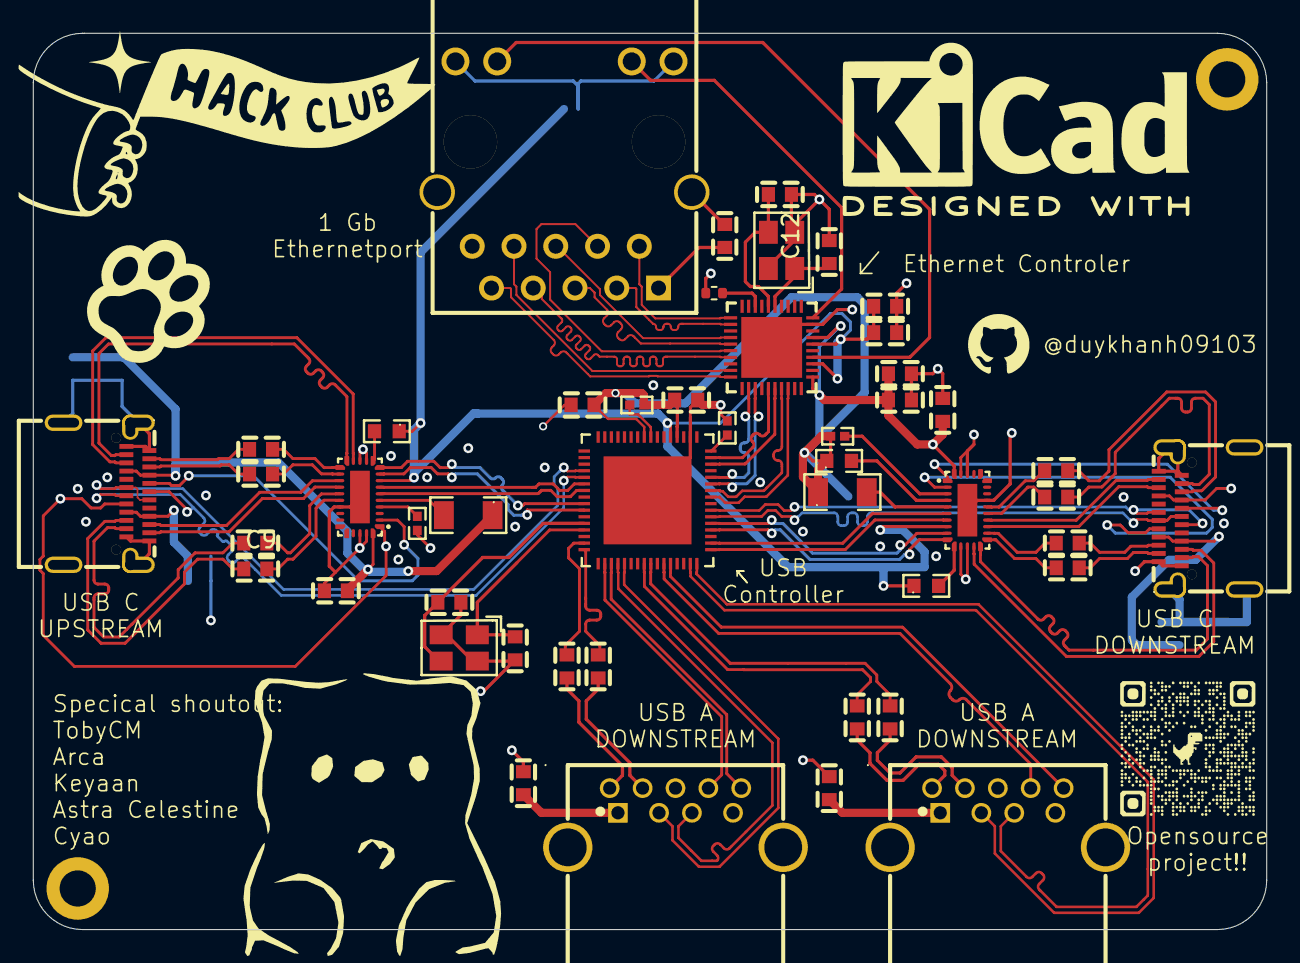
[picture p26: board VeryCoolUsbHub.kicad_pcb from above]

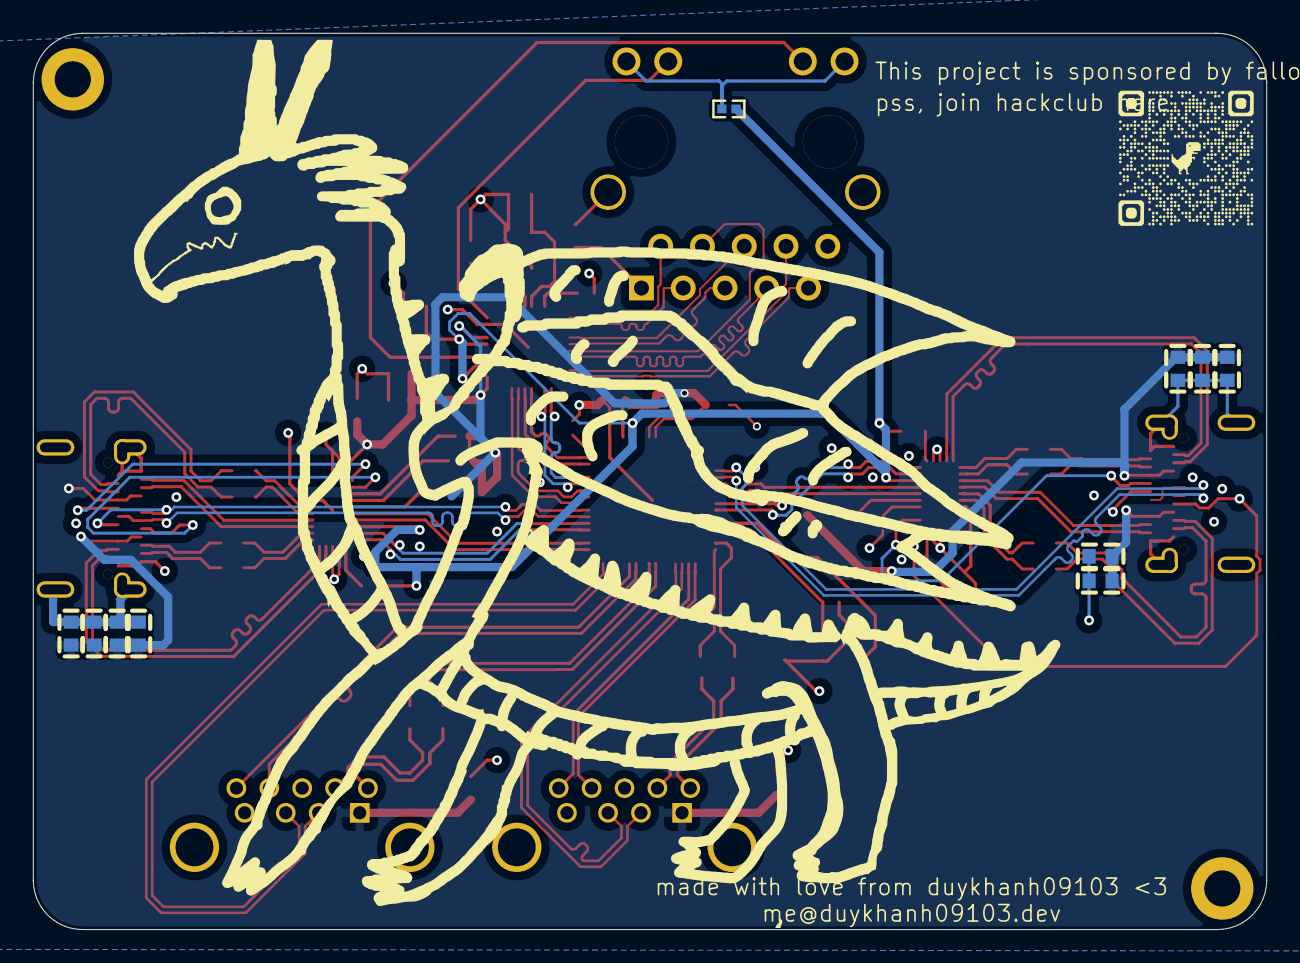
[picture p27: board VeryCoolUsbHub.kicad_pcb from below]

Board: 4 copper layers, 75.0 x 54.5 mm, 58 parts (10 on the bottom side), 91 nets.

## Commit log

2025-11-26 added jlc file
    [VeryCoolUsbHub.kicad_pcb, VeryCoolUsbHub.kicad_sch]
2025-11-26 changed stuff, add schem for review
    [VeryCoolUsbHub.kicad_sch]
2025-11-27 now with everything ig?
    [VeryCoolUsbHub.kicad_pcb, VeryCoolUsbHub.kicad_sch]
2025-11-27 done schem please
    [VeryCoolUsbHub.kicad_sch]
2025-11-27 fix kicad fucking up the save folder
2025-11-27 forgor to update schematic pdf
2025-11-27 forgor to link shield to ground
    [VeryCoolUsbHub.kicad_sch]
2025-11-28 do sum pcb
    [VeryCoolUsbHub.kicad_pcb, VeryCoolUsbHub.kicad_sch]
2026-05-19 do a lot of things
    [VeryCoolUsbHub.kicad_pcb, VeryCoolUsbHub.kicad_sch]
2026-05-20 BIG UPDATEEEEEEEEE
    [VeryCoolUsbHub.kicad_pcb, VeryCoolUsbHub.kicad_sch]
2026-05-22 please tell me this is the last time i need to reroute
    [VeryCoolUsbHub.kicad_pcb, VeryCoolUsbHub.kicad_sch]
2026-05-22 oops forgot to save
    [VeryCoolUsbHub.kicad_pcb]
2026-05-23 LETSGO THIS GONNA BE THE LAST TIME I ROUTE
    [VeryCoolUsbHub.kicad_pcb, VeryCoolUsbHub.kicad_sch]
2026-05-24 uhhh is this it?
    [bom.csv, designators.csv, positions.csv]
2026-05-24 i think im done with pcb
    [VeryCoolUsbHub.kicad_pcb]
2026-05-24 add VBUS plane to last layer
    [VeryCoolUsbHub.kicad_pcb]
2026-05-25 reroute a litlle bit of ethernet port
    [VeryCoolUsbHub.kicad_pcb, VeryCoolUsbHub.kicad_sch]
2026-05-26 hell yea? i hope its all
    [BOM.csv]
2026-05-27 fix connector and add case
    [VeryCoolUsbHub.kicad_pcb, case_bottom.step]
2026-05-28 change schen
    [VeryCoolUsbHub.kicad_sch]
2026-05-28 update case
    [case.step, case_bottom.step]
2026-06-04 fix some routing and add assembled case with pcb
    [Assembly_case.step, Assembly_honeycomb_case.step]
2026-06-04 forgor to update
    [VeryCoolUsbHub.kicad_pcb, VeryCoolUsbHub.kicad_sch]
2026-06-04 update schematic pdf
2026-06-14 fixed some signal intergrity problem
    [VeryCoolUsbHub.kicad_pcb, VeryCoolUsbHub.kicad_sch]
2026-06-14 update pcb image base on newest pcb
2026-06-16 fixed signal intergrity stuff
    [VeryCoolUsbHub.kicad_pcb]
2026-06-17 update Bom in readme
2026-06-18 update pcb and changed production file to newest
    [VeryCoolUsbHub.kicad_pcb, positions.csv]
2026-06-18 update zine and pcb image
2026-06-27 fixed small error in pcb
    [VeryCoolUsbHub.kicad_pcb, VeryCoolUsbHub.kicad_sch]
